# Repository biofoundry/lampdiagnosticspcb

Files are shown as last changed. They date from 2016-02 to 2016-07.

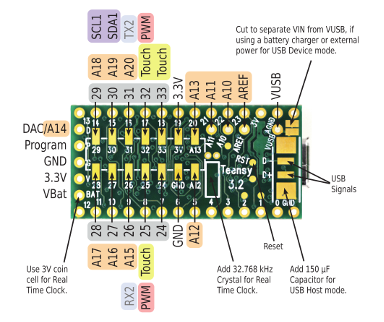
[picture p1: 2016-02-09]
Datasheets/teensy32_back_pinout.png

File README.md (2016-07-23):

# lampdiagnosticspcb
PCB Design for the LAMP Diagnostics device. Datasheets can be found in the Datasheet folder.

 My frist KiCAD project, sorry for any errors!

Based on a device built by Frank B. Myers, Richard H. Henrikson,Jennifer Bone and Luke P. Lee

http://journals.plos.org/plosone/article?id=10.1371/journal.pone.0070266
https://github.com/fbmyers/MicroBAR

This is a collaborative effort from bioHack Sydney and BioFoundry. 

Teensy's ADC / Voltage Reference
----------------

https://forum.pjrc.com/threads/27198-Using-External-AREF-with-ADC/page2

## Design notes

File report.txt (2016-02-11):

Info: Reading netlist file "/home/mat/lampdiagnosticspcb/projpcb.net".

Info: Using references to match components and footprints.

Info: Checking netlist component footprint "C1:/56B9C372:Capacitors_SMD:C_0805_HandSoldering".

Adding new component "C1:/56B9C372" footprint "Capacitors_SMD:C_0805_HandSoldering".

Changing component "C1:/56B9C372" pin "1" net name from "" to "VIN".

Changing component "C1:/56B9C372" pin "2" net name from "" to "GND".

Info: Checking netlist component footprint "C2:/56B9C865:Capacitors_SMD:C_0805_HandSoldering".

Adding new component "C2:/56B9C865" footprint "Capacitors_SMD:C_0805_HandSoldering".

Changing component "C2:/56B9C865" pin "1" net name from "" to "VIN".

Changing component "C2:/56B9C865" pin "2" net name from "" to "GND".

Info: Checking netlist component footprint "C3:/56B9CCA2:Capacitors_SMD:C_0805_HandSoldering".

Adding new component "C3:/56B9CCA2" footprint "Capacitors_SMD:C_0805_HandSoldering".

Changing component "C3:/56B9CCA2" pin "1" net name from "" to "+3V3".

Changing component "C3:/56B9CCA2" pin "2" net name from "" to "GND".

Info: Checking netlist component footprint "C4:/56B9CE8C:Capacitors_SMD:C_0805_HandSoldering".

Adding new component "C4:/56B9CE8C" footprint "Capacitors_SMD:C_0805_HandSoldering".

Changing component "C4:/56B9CE8C" pin "1" net name from "" to "+3V3".

Changing component "C4:/56B9CE8C" pin "2" net name from "" to "GND".

Info: Checking netlist component footprint "C5:/56B9CF34:Capacitors_SMD:C_0805_HandSoldering".

Adding new component "C5:/56B9CF34" footprint "Capacitors_SMD:C_0805_HandSoldering".

Changing component "C5:/56B9CF34" pin "1" net name from "" to "+3V3".

Changing component "C5:/56B9CF34" pin "2" net name from "" to "GND".

Info: Checking netlist component footprint "C6:/56B9E462:Capacitors_SMD:C_0805_HandSoldering".

Adding new component "C6:/56B9E462" footprint "Capacitors_SMD:C_0805_HandSoldering".

Changing component "C6:/56B9E462" pin "1" net name from "" to "+3V3".

Changing component "C6:/56B9E462" pin "2" net name from "" to "GND".

Info: Checking netlist component footprint "CON1:/56BA3485:Connect:BARREL_JACK".

Adding new component "CON1:/56BA3485" footprint "Connect:BARREL_JACK".

Changing component "CON1:/56BA3485" pin "1" net name from "" to "HEATER_PWR".

Changing component "CON1:/56BA3485" pin "2" net name from "" to "GND".

Changing component "CON1:/56BA3485" pin "3" net name from "" to "Net-(CON1-Pad3)".

Info: Checking netlist component footprint "CON2:/56BA4035:Connect:BARREL_JACK".

Adding new component "CON2:/56BA4035" footprint "Connect:BARREL_JACK".

Changing component "CON2:/56BA4035" pin "1" net name from "" to "HEATER_PWR".

Changing component "CON2:/56BA4035" pin "2" net name from "" to "Net-(CON2-Pad2)".

Changing component "CON2:/56BA4035" pin "3" net name from "" to "Net-(CON2-Pad3)".

Info: Checking netlist component footprint "P1:/56BA5A45:Pin_Headers:Pin_Header_Straight_1x02".

Adding new component "P1:/56BA5A45" footprint "Pin_Headers:Pin_Header_Straight_1x02".

Changing component "P1:/56BA5A45" pin "1" net name from "" to "VIN".

Changing component "P1:/56BA5A45" pin "2" net name from "" to "TEMP_S".

Info: Checking netlist component footprint "P2:/56BA95A4:Pin_Headers:Pin_Header_Angled_1x02".

Adding new component "P2:/56BA95A4" footprint "Pin_Headers:Pin_Header_Angled_1x02".

Changing component "P2:/56BA95A4" pin "1" net name from "" to "GND".

Changing component "P2:/56BA95A4" pin "2" net name from "" to "Net-(P2-Pad2)".

Info: Checking netlist component footprint "Q1:/56B9494D/56B94958:Resistors_SMD:R_0805_HandSoldering".

Adding new component "Q1:/56B9494D/56B94958" footprint "Resistors_SMD:R_0805_HandSoldering".

Changing component "Q1:/56B9494D/56B94958" pin "1" net name from "" to "/Phototransistors/S1".

Changing component "Q1:/56B9494D/56B94958" pin "2" net name from "" to "+3V3".

Info: Checking netlist component footprint "Q2:/56B9494D/56B94C7F:Resistors_SMD:R_0805_HandSoldering".

Adding new component "Q2:/56B9494D/56B94C7F" footprint "Resistors_SMD:R_0805_HandSoldering".

Changing component "Q2:/56B9494D/56B94C7F" pin "1" net name from "" to "/Phototransistors/S2".

Changing component "Q2:/56B9494D/56B94C7F" pin "2" net name from "" to "+3V3".

Info: Checking netlist component footprint "Q3:/56B9494D/56B94FE9:Resistors_SMD:R_0805_HandSoldering".

Adding new component "Q3:/56B9494D/56B94FE9" footprint "Resistors_SMD:R_0805_HandSoldering".

Changing component "Q3:/56B9494D/56B94FE9" pin "1" net name from "" to "/Phototransistors/S3".

Changing component "Q3:/56B9494D/56B94FE9" pin "2" net name from "" to "+3V3".

Info: Checking netlist component footprint "Q4:/56B9494D/56B950F7:Resistors_SMD:R_0805_HandSoldering".

Adding new component "Q4:/56B9494D/56B950F7" footprint "Resistors_SMD:R_0805_HandSoldering".

Changing component "Q4:/56B9494D/56B950F7" pin "1" net name from "" to "/Phototransistors/S4".

Changing component "Q4:/56B9494D/56B950F7" pin "2" net name from "" to "+3V3".

Info: Checking netlist component footprint "Q5:/56B9494D/56B951F6:Resistors_SMD:R_0805_HandSoldering".

Adding new component "Q5:/56B9494D/56B951F6" footprint "Resistors_SMD:R_0805_HandSoldering".

Changing component "Q5:/56B9494D/56B951F6" pin "1" net name from "" to "/Phototransistors/S5".

Changing component "Q5:/56B9494D/56B951F6" pin "2" net name from "" to "+3V3".

Info: Checking netlist component footprint "Q6:/56B9494D/56B94A26:Resistors_SMD:R_0805_HandSoldering".

Adding new component "Q6:/56B9494D/56B94A26" footprint "Resistors_SMD:R_0805_HandSoldering".

Changing component "Q6:/56B9494D/56B94A26" pin "1" net name from "" to "+3V3".

Changing component "Q6:/56B9494D/56B94A26" pin "2" net name from "" to "/Phototransistors/S6".

Info: Checking netlist component footprint "Q7:/56B9494D/56B94CFB:Resistors_SMD:R_0805_HandSoldering".

Adding new component "Q7:/56B9494D/56B94CFB" footprint "Resistors_SMD:R_0805_HandSoldering".

Changing component "Q7:/56B9494D/56B94CFB" pin "1" net name from "" to "/Phototransistors/S7".

Changing component "Q7:/56B9494D/56B94CFB" pin "2" net name from "" to "+3V3".

Info: Checking netlist component footprint "Q8:/56B9494D/56B94FEF:Resistors_SMD:R_0805_HandSoldering".

Adding new component "Q8:/56B9494D/56B94FEF" footprint "Resistors_SMD:R_0805_HandSoldering".

Changing component "Q8:/56B9494D/56B94FEF" pin "1" net name from "" to "/Phototransistors/S8".

Changing component "Q8:/56B9494D/56B94FEF" pin "2" net name from "" to "+3V3".

Info: Checking netlist component footprint "Q9:/56B9494D/56B950FD:Resistors_SMD:R_0805_HandSoldering".

Adding new component "Q9:/56B9494D/56B950FD" footprint "Resistors_SMD:R_0805_HandSoldering".

Changing component "Q9:/56B9494D/56B950FD" pin "1" net name from "" to "/Phototransistors/S9".

Changing component "Q9:/56B9494D/56B950FD" pin "2" net name from "" to "+3V3".

Info: Checking netlist component footprint "Q10:/56B9494D/56B951FC:Resistors_SMD:R_0805_HandSoldering".

Adding new component "Q10:/56B9494D/56B951FC" footprint "Resistors_SMD:R_0805_HandSoldering".

Changing component "Q10:/56B9494D/56B951FC" pin "1" net name from "" to "/Phototransistors/S10".

Changing component "Q10:/56B9494D/56B951FC" pin "2" net name from "" to "+3V3".

Info: Checking netlist component footprint "Q11:/56B9494D/56B94A86:Resistors_SMD:R_0805_HandSoldering".

Adding new component "Q11:/56B9494D/56B94A86" footprint "Resistors_SMD:R_0805_HandSoldering".

Changing component "Q11:/56B9494D/56B94A86" pin "1" net name from "" to "+3V3".

Changing component "Q11:/56B9494D/56B94A86" pin "2" net name from "" to "/Phototransistors/S11".

Info: Checking netlist component footprint "Q12:/56B9494D/56B94D59:Resistors_SMD:R_0805_HandSoldering".

Adding new component "Q12:/56B9494D/56B94D59" footprint "Resistors_SMD:R_0805_HandSoldering".

Changing component "Q12:/56B9494D/56B94D59" pin "1" net name from "" to "/Phototransistors/S12".

Changing component "Q12:/56B9494D/56B94D59" pin "2" net name from "" to "+3V3".

Info: Checking netlist component footprint "Q13:/56B9494D/56B94FF5:Resistors_SMD:R_0805_HandSoldering".

Adding new component "Q13:/56B9494D/56B94FF5" footprint "Resistors_SMD:R_0805_HandSoldering".

Changing component "Q13:/56B9494D/56B94FF5" pin "1" net name from "" to "/Phototransistors/S13".

Changing component "Q13:/56B9494D/56B94FF5" pin "2" net name from "" to "+3V3".

Info: Checking netlist component footprint "Q14:/56B9494D/56B95103:Resistors_SMD:R_0805_HandSoldering".

Adding new component "Q14:/56B9494D/56B95103" footprint "Resistors_SMD:R_0805_HandSoldering".

Changing component "Q14:/56B9494D/56B95103" pin "1" net name from "" to "/Phototransistors/S14".

Changing component "Q14:/56B9494D/56B95103" pin "2" net name from "" to "+3V3".

Info: Checking netlist component footprint "Q15:/56B9494D/56B95202:Resistors_SMD:R_0805_HandSoldering".

Adding new component "Q15:/56B9494D/56B95202" footprint "Resistors_SMD:R_0805_HandSoldering".

Changing component "Q15:/56B9494D/56B95202" pin "1" net name from "" to "/Phototransistors/S15".

Changing component "Q15:/56B9494D/56B95202" pin "2" net name from "" to "+3V3".

Info: Checking netlist component footprint "Q16:/56BA1661:TO_SOT_Packages_SMD:SOT-23_Handsoldering".

Adding new component "Q16:/56BA1661" footprint "TO_SOT_Packages_SMD:SOT-23_Handsoldering".

Changing component "Q16:/56BA1661" pin "1" net name from "" to "HEAT".

Changing component "Q16:/56BA1661" pin "2" net name from "" to "GND".

Changing component "Q16:/56BA1661" pin "3" net name from "" to "Net-(CON2-Pad2)".

Info: Checking netlist component footprint "R1:/56B99A73:Resistors_SMD:R_0805_HandSoldering".

Adding new component "R1:/56B99A73" footprint "Resistors_SMD:R_0805_HandSoldering".

Changing component "R1:/56B99A73" pin "1" net name from "" to "Net-(R1-Pad1)".

Changing component "R1:/56B99A73" pin "2" net name from "" to "GND".

Info: Checking netlist component footprint "R2:/56BA539F:Resistors_SMD:R_0805_HandSoldering".

Adding new component "R2:/56BA539F" footprint "Resistors_SMD:R_0805_HandSoldering".

Changing component "R2:/56BA539F" pin "1" net name from "" to "TEMP_S".

Changing component "R2:/56BA539F" pin "2" net name from "" to "GND".

Info: Checking netlist component footprint "RV1:/56B99053:Potentiometers:Potentiometer_Trimmer-Suntan-TSR-3386P".

Adding new component "RV1:/56B99053" footprint "Potentiometers:Potentiometer_Trimmer-Suntan-TSR-3386P".

Changing component "RV1:/56B99053" pin "3" net name from "" to "Net-(RV1-Pad3)".

Changing component "RV1:/56B99053" pin "1" net name from "" to "Net-(R1-Pad1)".

Changing component "RV1:/56B99053" pin "2" net name from "" to "Net-(R1-Pad1)".

Info: Checking netlist component footprint "RV2:/56B985A4:Potentiometers:Potentiometer_Trimmer-Suntan-TSR-3386P".

Adding new component "RV2:/56B985A4" footprint "Potentiometers:Potentiometer_Trimmer-Suntan-TSR-3386P".

Changing component "RV2:/56B985A4" pin "3" net name from "" to "GND".

Changing component "RV2:/56B985A4" pin "1" net name from "" to "Net-(RV2-Pad1)".

Changing component "RV2:/56B985A4" pin "2" net name from "" to "Net-(RV2-Pad1)".

Info: Checking netlist component footprint "U1:/56B935F7:Teensy-3:Teensy-3.1".

Adding new component "U1:/56B935F7" footprint "Teensy-3:Teensy-3.1".

Changing component "U1:/56B935F7" pin "0" net name from "" to "Net-(U1-Pad0)".

Changing component "U1:/56B935F7" pin "1" net name from "" to "Net-(U1-Pad1)".

Changing component "U1:/56B935F7" pin "2" net name from "" to "T2".

Changing component "U1:/56B935F7" pin "3" net name from "" to "T3".

Changing component "U1:/56B935F7" pin "4" net name from "" to "T4".

Changing component "U1:/56B935F7" pin "5" net name from "" to "T5".

Changing component "U1:/56B935F7" pin "6" net name from "" to "T6".

Changing component "U1:/56B935F7" pin "7" net name from "" to "HEAT".

Changing component "U1:/56B935F7" pin "8" net name from "" to "Net-(U1-Pad8)".

Changing component "U1:/56B935F7" pin "9" net name from "" to "Net-(U1-Pad9)".

Changing component "U1:/56B935F7" pin "10" net name from "" to "Net-(U1-Pad10)".

Changing component "U1:/56B935F7" pin "11" net name from "" to "Net-(U1-Pad11)".

Changing component "U1:/56B935F7" pin "12" net name from "" to "Net-(U1-Pad12)".

Changing component "U1:/56B935F7" pin "13" net name from "" to "Net-(U1-Pad13)".

Changing component "U1:/56B935F7" pin "14" net name from "" to "Net-(U1-Pad14)".

Changing component "U1:/56B935F7" pin "15" net name from "" to "Net-(U1-Pad15)".

Changing component "U1:/56B935F7" pin "16" net name from "" to "Net-(U1-Pad16)".

Changing component "U1:/56B935F7" pin "17" net name from "" to "Net-(U1-Pad17)".

Changing component "U1:/56B935F7" pin "18" net name from "" to "Net-(U1-Pad18)".

Changing component "U1:/56B935F7" pin "19" net name from "" to "Net-(U1-Pad19)".

Changing component "U1:/56B935F7" pin "20" net name from "" to "Net-(RV1-Pad3)".

Changing component "U1:/56B935F7" pin "21" net name from "" to "TEMP_S".

Changing component "U1:/56B935F7" pin "22" net name from "" to "Net-(U1-Pad22)".

Changing component "U1:/56B935F7" pin "23" net name from "" to "Net-(U1-Pad23)".

Changing component "U1:/56B935F7" pin "24" net name from "" to "Net-(U1-Pad24)".

Changing component "U1:/56B935F7" pin "25" net name from "" to "Net-(U1-Pad25)".

Changing component "U1:/56B935F7" pin "26" net name from "" to "VIN".

Changing component "U1:/56B935F7" pin "27" net name from "" to "Net-(U1-Pad27)".

Info: Checking netlist component footprint "U2:/56B98142:Housings_DIP:DIP-8_W7.62mm".

Adding new component "U2:/56B98142" footprint "Housings_DIP:DIP-8_W7.62mm".

Changing component "U2:/56B98142" pin "1" net name from "" to "Net-(RV1-Pad3)".

Changing component "U2:/56B98142" pin "2" net name from "" to "Net-(R1-Pad1)".

Changing component "U2:/56B98142" pin "3" net name from "" to "Net-(RV2-Pad1)".

Changing component "U2:/56B98142" pin "4" net name from "" to "VIN".

Changing component "U2:/56B98142" pin "8" net name from "" to "GND".

Info: Checking netlist component footprint "U3:/56B96E51:Housings_DIP:DIP-24_W10.16mm".

Adding new component "U3:/56B96E51" footprint "Housings_DIP:DIP-24_W10.16mm".

Changing component "U3:/56B96E51" pin "1" net name from "" to "Net-(RV2-Pad1)".

Changing component "U3:/56B96E51" pin "2" net name from "" to "/Phototransistors/S8".

Changing component "U3:/56B96E51" pin "3" net name from "" to "/Phototransistors/S7".

Changing component "U3:/56B96E51" pin "4" net name from "" to "/Phototransistors/S6".

Changing component "U3:/56B96E51" pin "5" net name from "" to "/Phototransistors/S5".

Changing component "U3:/56B96E51" pin "6" net name from "" to "/Phototransistors/S4".

Changing component "U3:/56B96E51" pin "7" net name from "" to "/Phototransistors/S3".

Changing component "U3:/56B96E51" pin "8" net name from "" to "/Phototransistors/S2".

Changing component "U3:/56B96E51" pin "9" net name from "" to "/Phototransistors/S1".

Changing component "U3:/56B96E51" pin "10" net name from "" to "T2".

Changing component "U3:/56B96E51" pin "11" net name from "" to "T3".

Changing component "U3:/56B96E51" pin "12" net name from "" to "GND".

Changing component "U3:/56B96E51" pin "13" net name from "" to "T5".

Changing component "U3:/56B96E51" pin "14" net name from "" to "T4".

Changing component "U3:/56B96E51" pin "15" net name from "" to "T6".

Changing component "U3:/56B96E51" pin "16" net name from "" to "Net-(U3-Pad16)".

Changing component "U3:/56B96E51" pin "17" net name from "" to "/Phototransistors/S15".

Changing component "U3:/56B96E51" pin "18" net name from "" to "/Phototransistors/S14".

Changing component "U3:/56B96E51" pin "19" net name from "" to "/Phototransistors/S13".

Changing component "U3:/56B96E51" pin "20" net name from "" to "/Phototransistors/S12".

Changing component "U3:/56B96E51" pin "21" net name from "" to "/Phototransistors/S11".

Changing component "U3:/56B96E51" pin "22" net name from "" to "/Phototransistors/S10".

Changing component "U3:/56B96E51" pin "23" net name from "" to "/Phototransistors/S9".

Changing component "U3:/56B96E51" pin "24" net name from "" to "VIN".

Info: Checking netlist component footprint "U4:/56BA8B71:TO_SOT_Packages_THT:TO-92_Inline_Narrow_Oval".

Adding new component "U4:/56BA8B71" footprint "TO_SOT_Packages_THT:TO-92_Inline_Narrow_Oval".

Changing component "U4:/56BA8B71" pin "2" net name from "" to "Net-(P2-Pad2)".

Changing component "U4:/56BA8B71" pin "3" net name from "" to "VIN".

Changing component "U4:/56BA8B71" pin "1" net name from "" to "GND".

Error: Component 'U1' pad '30' not found in footprint 'Teensy-3:Teensy-3.1'

Error: Component 'U1' pad '31' not found in footprint 'Teensy-3:Teensy-3.1'

Error: Component 'U1' pad '29' not found in footprint 'Teensy-3:Teensy-3.1'

Error: Component 'U1' pad '28' not found in footprint 'Teensy-3:Teensy-3.1'

Error: Component 'U1' pad '32' not found in footprint 'Teensy-3:Teensy-3.1'

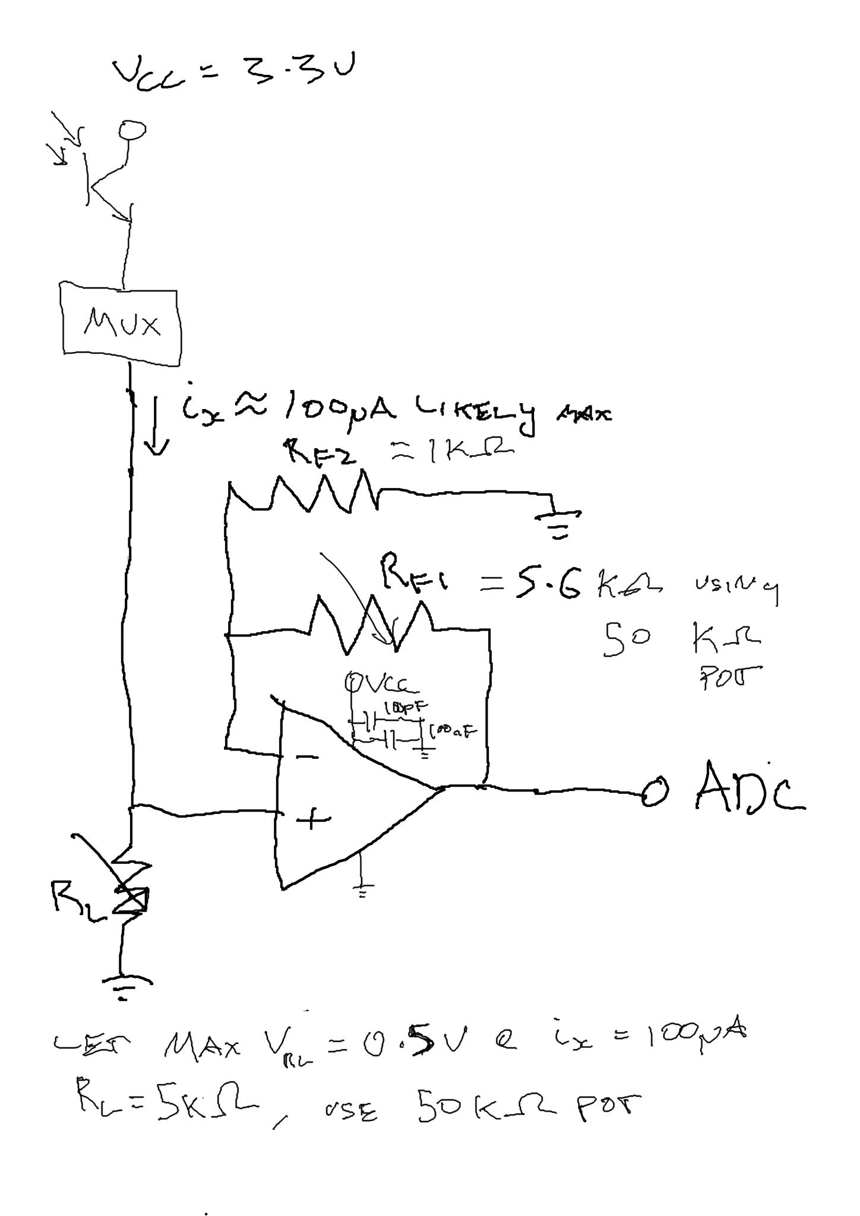
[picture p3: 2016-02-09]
Datasheets/InitialOpAmpLayout.jpg

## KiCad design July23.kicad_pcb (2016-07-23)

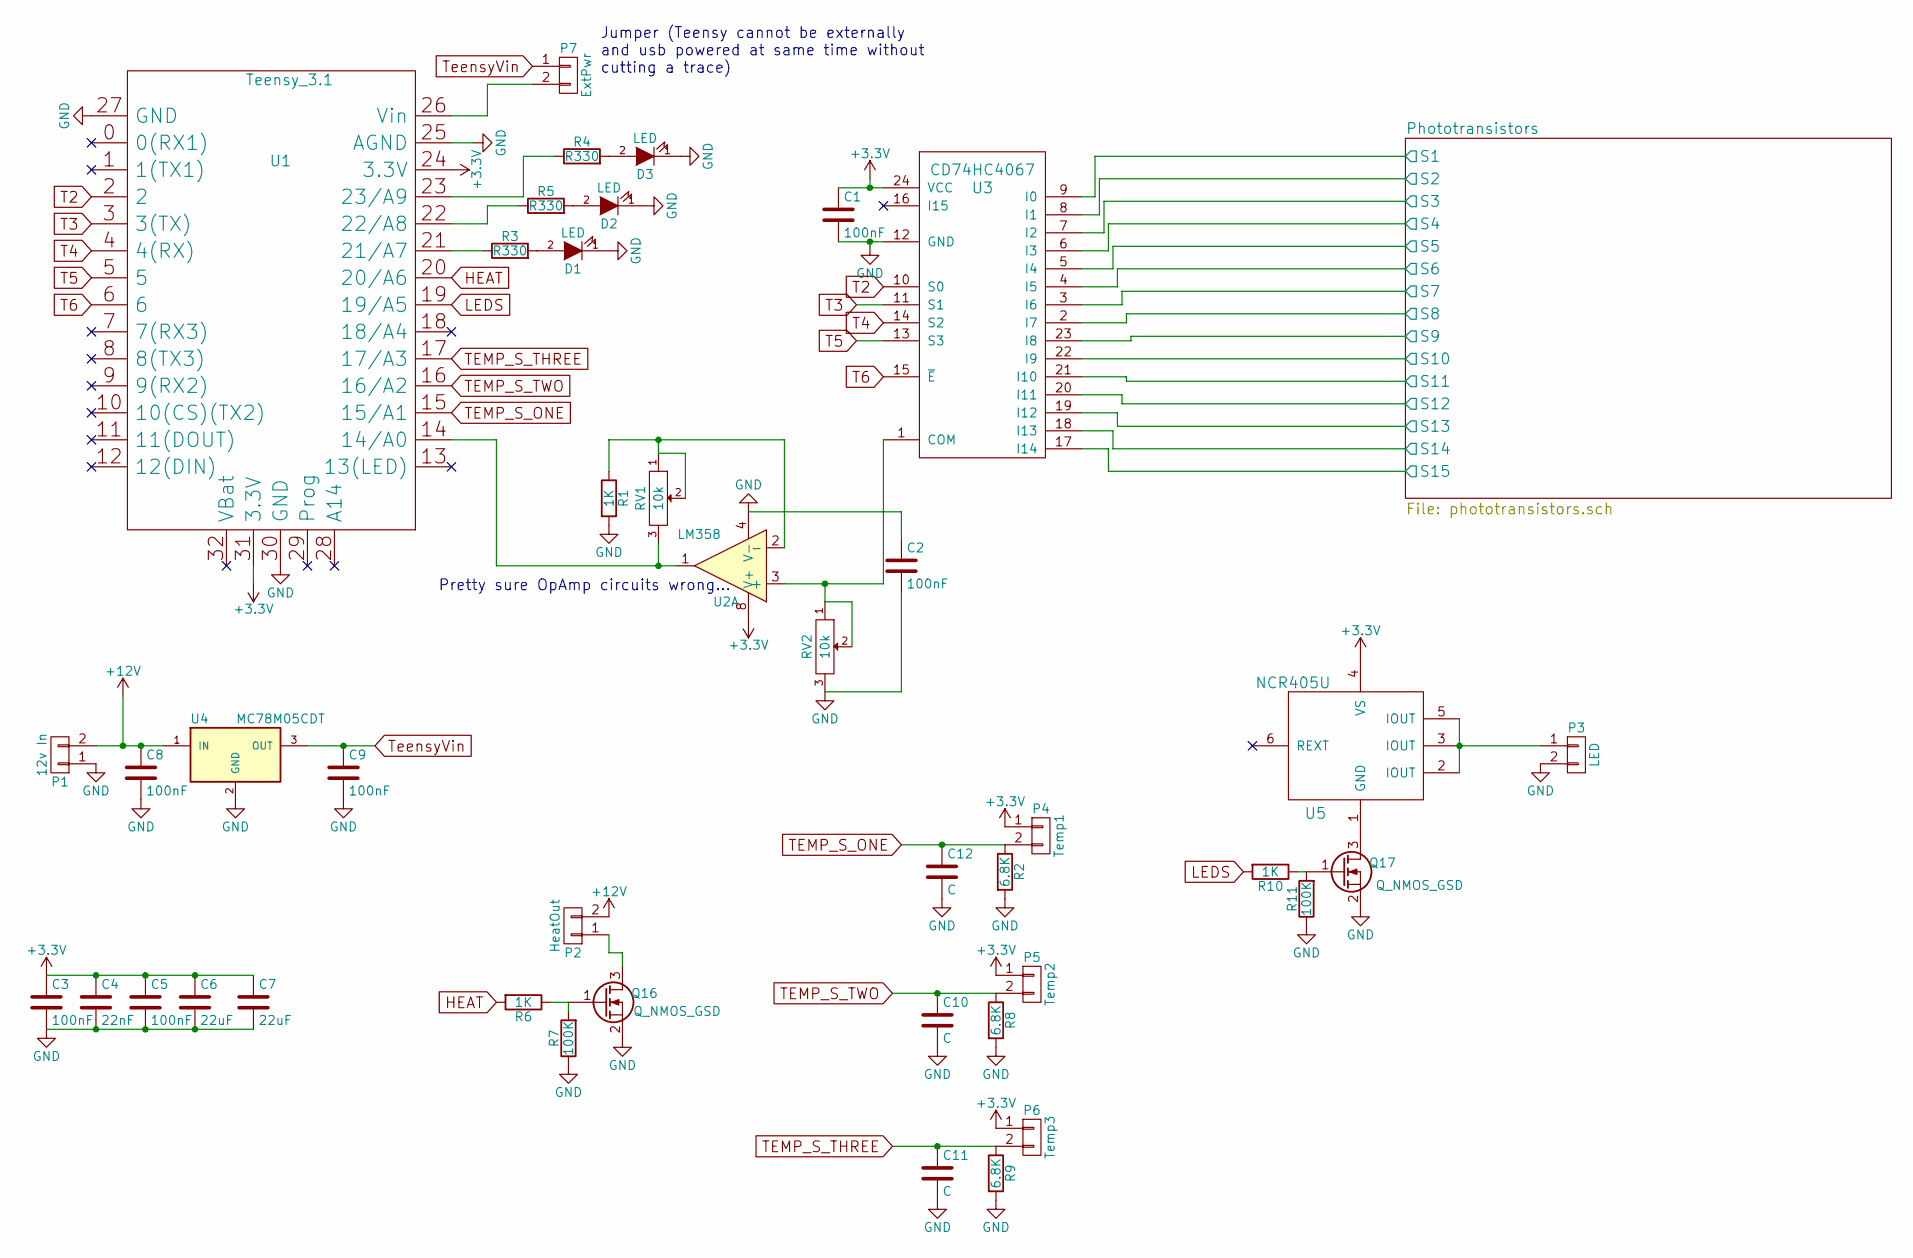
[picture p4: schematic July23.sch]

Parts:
C1, C2, C3, C5, C8, C9: 100nF; C_0805_HandSoldering
C4: 22nF; C_0805_HandSoldering
C6, C7: 22uF; C_0805_HandSoldering
C10, C11, C12: C; C_0805_HandSoldering
D1, D2, D3: LED; LED_0805
P1: 12v In; 2_5mm_screw_terminal
P2: HeatOut; 2_5mm_screw_terminal
P3: LED; 2_5mm_screw_terminal
P4: Temp1; 2_5mm_screw_terminal
P5: Temp2; 2_5mm_screw_terminal
P6: Temp3; 2_5mm_screw_terminal
P7: ExtPwr; Pin_Header_Straight_1x02
Q16, Q17: Q_NMOS_GSD; SOT-23_Handsoldering
R1, R6, R10: 1K; R_0805_HandSoldering
R2, R8, R9: 6.8K; R_0805_HandSoldering
R3, R4, R5: R330; R_0805_HandSoldering
R7, R11: 100K; R_0805_HandSoldering
RV1, RV2: 10k; Potentiometer_Trimmer-Suntan-TSR-3386P
U1: Teensy_3.1; Teensy-3.1
U2: LM358; DIP-8_W7.62mm
U3: CD74HC4067; DIP-24_W10.16mm
U4: MC78M05CDT; TO-252-2Lead
U5: NCR405U; SOT457

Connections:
+12V: C8.1, P1.2, P2.2, U4.1 (IN)
/Phototransistors/S1: U3.9 (I0); also elsewhere on the board
/Phototransistors/S2: U3.8 (I1); also elsewhere on the board
/Phototransistors/S3: U3.7 (I2); also elsewhere on the board
/Phototransistors/S4: U3.6 (I3); also elsewhere on the board
/Phototransistors/S5: U3.5 (I4); also elsewhere on the board
/Phototransistors/S6: U3.4 (I5); also elsewhere on the board
/Phototransistors/S7: U3.3 (I6); also elsewhere on the board
/Phototransistors/S8: U3.2 (I7); also elsewhere on the board
/Phototransistors/S9: U3.23 (I8); also elsewhere on the board
/Phototransistors/S10: U3.22 (I9); also elsewhere on the board
/Phototransistors/S11: U3.21 (I10); also elsewhere on the board
/Phototransistors/S12: U3.20 (I11); also elsewhere on the board
/Phototransistors/S13: U3.19 (I12); also elsewhere on the board
/Phototransistors/S14: U3.18 (I13); also elsewhere on the board
/Phototransistors/S15: U3.17 (I14); also elsewhere on the board
HEAT: R6.2, U1.20 (20/A6)
LEDS: R10.2, U1.19 (19/A5)
unnamed: D1.2 (A), R3.2
unnamed: D2.2 (A), R5.2
unnamed: D3.2 (A), R4.2
unnamed: P2.1, Q16.3 (D)
unnamed: P3.1, U5.2 (IOUT), U5.3 (IOUT), U5.5 (IOUT)
unnamed: P7.2, U1.26 (Vin)
unnamed: Q16.1 (G), R6.1, R7.2
unnamed: Q17.1 (G), R10.1, R11.2
unnamed: Q17.3 (D), U5.1 (GND)
unnamed: R1.1, RV1.1, RV1.2, U2.2 (-)
unnamed: R3.1, U1.21 (21/A7)
unnamed: R4.1, U1.23 (23/A9)
unnamed: R5.1, U1.22 (22/A8)
unnamed: RV1.3, U1.14 (14/A0), U2.1
unnamed: RV2.1, RV2.2, U2.3 (+), U3.1 (COM)
T2: U1.2, U3.10 (S0)
T3: U1.3 (3(TX)), U3.11 (S1)
T4: U1.4 (4(RX)), U3.14 (S2)
T5: U1.5, U3.13 (S3)
T6: U1.6, U3.15 (~E)
TEMP_S_ONE: C12.1, P4.2, R2.1, U1.15 (15/A1)
TEMP_S_THREE: C11.1, P6.2, R9.1, U1.17 (17/A3)
TEMP_S_TWO: C10.1, P5.2, R8.1, U1.16 (16/A2)
TeensyVin: C9.1, P7.1, U4.3 (OUT)

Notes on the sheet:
Jumper (Teensy cannot be externally and usb powered at same time without cutting a trace)
Pretty sure OpAmp circuits wrong...

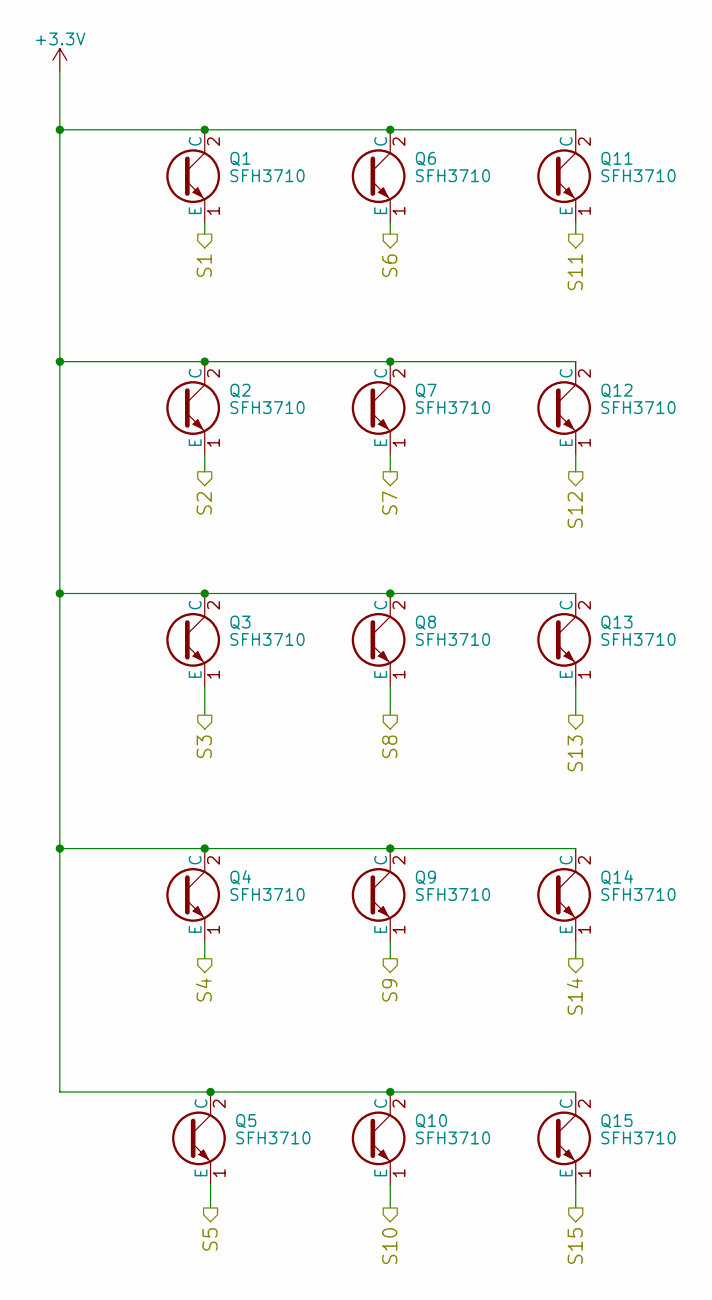
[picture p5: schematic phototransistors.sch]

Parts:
Q1, Q2, Q3, Q4, Q5, Q6, Q7, Q8, Q9, Q10, Q11, Q12, Q13, Q14, Q15: SFH3710; R_0805_HandSoldering

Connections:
/Phototransistors/S1: Q1.1 (E); also elsewhere on the board
/Phototransistors/S2: Q2.1 (E); also elsewhere on the board
/Phototransistors/S3: Q3.1 (E); also elsewhere on the board
/Phototransistors/S4: Q4.1 (E); also elsewhere on the board
/Phototransistors/S5: Q5.1 (E); also elsewhere on the board
/Phototransistors/S6: Q6.1 (E); also elsewhere on the board
/Phototransistors/S7: Q7.1 (E); also elsewhere on the board
/Phototransistors/S8: Q8.1 (E); also elsewhere on the board
/Phototransistors/S9: Q9.1 (E); also elsewhere on the board
/Phototransistors/S10: Q10.1 (E); also elsewhere on the board
/Phototransistors/S11: Q11.1 (E); also elsewhere on the board
/Phototransistors/S12: Q12.1 (E); also elsewhere on the board
/Phototransistors/S13: Q13.1 (E); also elsewhere on the board
/Phototransistors/S14: Q14.1 (E); also elsewhere on the board
/Phototransistors/S15: Q15.1 (E); also elsewhere on the board

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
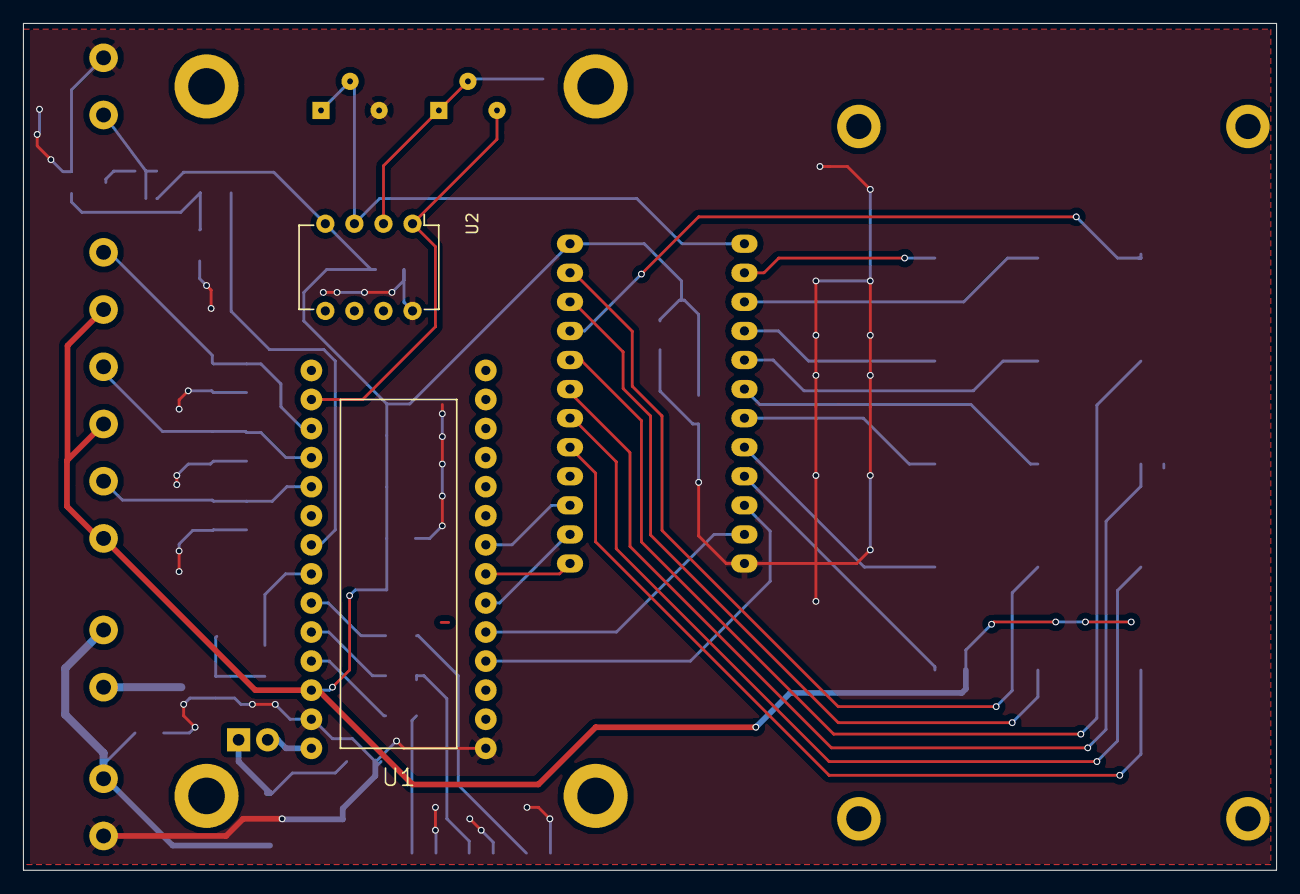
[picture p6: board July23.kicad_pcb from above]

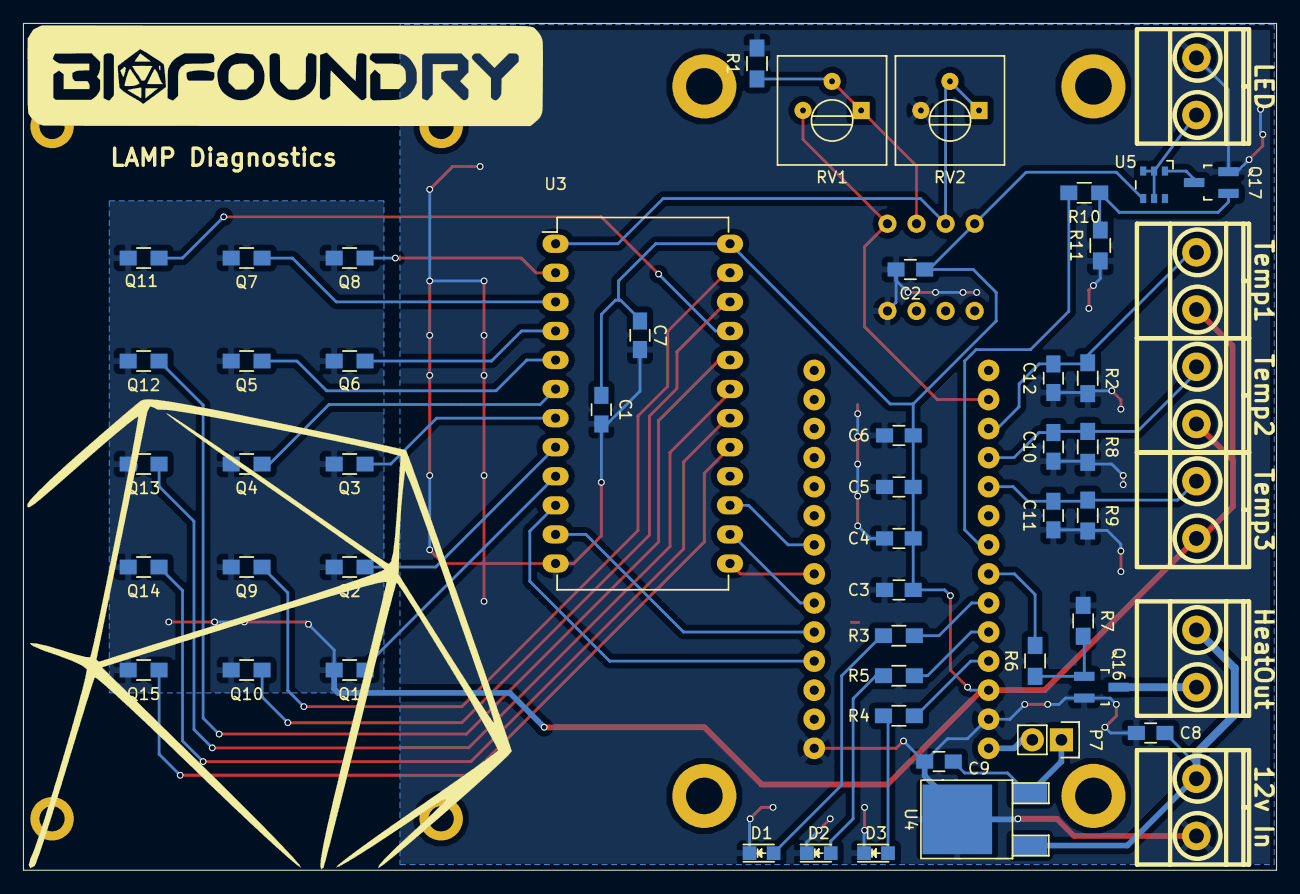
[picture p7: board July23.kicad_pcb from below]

Board: 2 copper layers, 109.5 x 74.0 mm, 57 parts (55 on the bottom side), 44 nets.

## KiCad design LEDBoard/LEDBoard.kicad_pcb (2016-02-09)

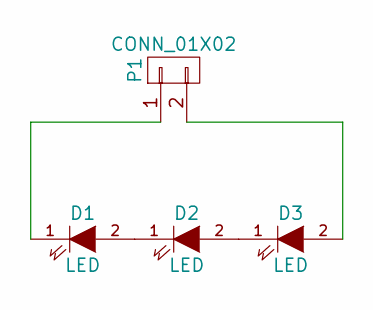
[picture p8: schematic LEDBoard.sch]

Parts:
D1, D2, D3: LED; LED-5MM
P1: CONN_01X02; Pin_Header_Straight_1x02

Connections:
unnamed: D1.1 (K), P1.1
unnamed: D1.2 (A), D2.1 (K)
unnamed: D2.2 (A), D3.1 (K)
unnamed: D3.2 (A), P1.2

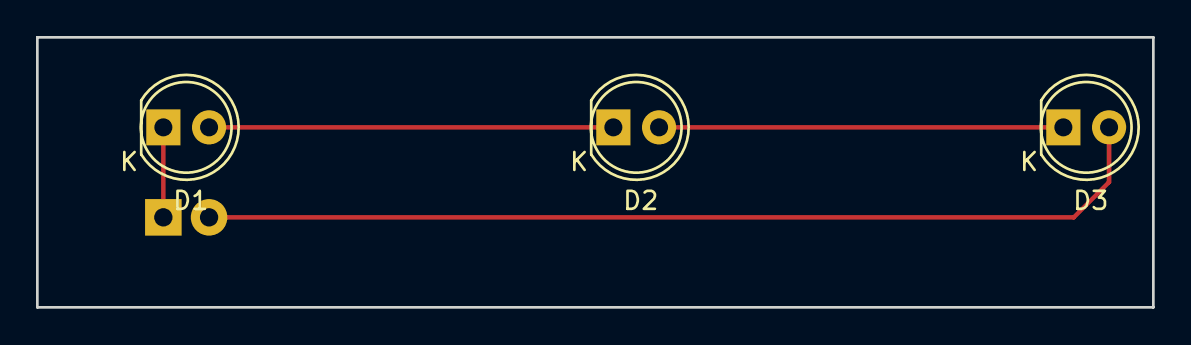
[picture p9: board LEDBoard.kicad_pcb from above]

Board: 2 copper layers, 62.0 x 15.0 mm, 4 parts (1 on the bottom side), 4 nets.

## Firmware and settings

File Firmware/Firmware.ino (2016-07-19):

/*

LAMP Diagnostics qPCR Device
Created by BioFoundry

Contributers --Mat(fluffeh) Neal -- Tom -- Sophie -- Meow -- Nicole -- James -- 

Status LEDS's Green(15) Blue(14) Red (16)
 
 */
 
// Pin 13 has an LED connected on most Arduino boards.
// Pin 11 has the LED on Teensy 2.0
// Pin 6  has the LED on Teensy++ 2.0
// Pin 13 has the LED on Teensy 3.0
// give it a name:

int ledG = 15;
int ledB = 14;
int ledR = 16;

// the setup routine runs once when you press reset:
void setup() {                
  // initialize the digital pin as an output.
  pinMode(ledR, OUTPUT);
  pinMode(ledG, OUTPUT);    
  pinMode(ledB, OUTPUT);     

  delay(500);

  digitalWrite(ledR, HIGH);  
  delay(1000);               
  digitalWrite(ledR, LOW);   


  digitalWrite(ledG, HIGH);  
  delay(1000);               
  digitalWrite(ledG, LOW);   


  digitalWrite(ledB, HIGH);  
  delay(1000);               
  digitalWrite(ledB, LOW);   

                 
}

// the loop routine runs over and over again forever:
void loop() {
  digitalWrite(ledR, HIGH);  
  delay(50);               
  digitalWrite(ledR, LOW);

  digitalWrite(ledG, HIGH);  
  delay(50);               
  digitalWrite(ledG, LOW);  

  digitalWrite(ledB, HIGH);  
  delay(50);               
  digitalWrite(ledB, LOW); 

  


 
}

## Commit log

2016-02-09 Created project file
    [projpcb.kicad_pcb, projpcb.sch]
2016-02-09 New footprint for teensy
2016-02-09 schematic so far
    [phototransistors.sch, projpcb.sch]
2016-02-09 Progress on schematic, phototransistor array + analog frontend complete
    [phototransistors.sch, projpcb.sch]
2016-02-09 Draft version v1 of Schematic
    [phototransistors.sch, projpcb.sch]
2016-02-11 Board design V1
    [projpcb.kicad_pcb, projpcb.sch]
2016-02-20 Added breakout headers for phototransistors, added GNDA for analog aspects
    [_saved_projpcb.sch, pcbSpaced.kicad_pcb, phototransistors.sch]
2016-02-24 Changed VIN --> 3.3v, analog GND to AGND, added 3 status LED's
    [_saved_projpcb.sch, phototransistors.sch, projpcb.kicad_pcb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]
2016-02-24 PCB furtherererd
    [projpcb.kicad_pcb]
2016-03-11 VERSION ONE - Sent for manufacturegit add -Agit add -A
    [DONNE-B.Cu.gbl, DONNE-B.Mask.gbs, DONNE-B.SilkS.gbo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]
2016-07-19 Added missing pot, logos and mounting holes.
    [July18.kicad_pcb, phototransistors.sch, projpcb.sch]
2016-07-19 Deleted redundant files. July 18 Pro / Board files are latest. Next step is firmware
    [DONNE.kicad_pcb, Done??.kicad_pcb, pcbSpaced.kicad_pcb]
2016-07-19 More via stitching, more bypass for mux
    [July18.kicad_pcb, phototransistors.sch, projpcb.sch]
2016-07-19 Blarg, KiCAD crashed, redoing all before, repushing often
    [July18.kicad_pcb]
2016-07-21 Big revamp
    Added mosfet to LED output
    Changed LED driver to NCR405U
    Changed phototransistor array to be 9mm * 9mm to match standard 96 well
    sizing
    Added 5v Linear reg to feed the teensy as well as a jumper so we can do
    initial tests using usb power
    [July18.kicad_pcb, phototransistors.sch, projpcb.sch]
2016-07-21 Added Name ^.^
    [July18.kicad_pcb]
2016-07-22 Moved via ^.^
    [July18.kicad_pcb]
2016-07-23 Cleaned up Old files
    [July18.kicad_pcb, July23.kicad_pcb, July23.sch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]
2016-07-23 Changed schematic of SFH3710
    [July23.kicad_pcb, July23.sch, phototransistors.sch]
2016-07-23 OpAmp circuit needs checking
    [July23.kicad_pcb, July23.sch]
2016-07-26 opamp flipped for clarity
    [July23.sch]
2016-07-26 fixing up opamp on PCB (work in progress)
    [July23.kicad_pcb, July23.sch]
2016-07-28 improved Gnd stitching
    unused part of LM358 still to be connected somewhere
    [July23.kicad_pcb]
2016-07-30 bigger 3v3 tracks
    not sure if LED supply is better or worse now - it's away from the opamp (that's good), but now might cause interference on the temp. sensors (that's bad).
    If LED isn't switched much, and/or if temperature accuracy isn't critical, this layout should be OK.
    Might still be worth moving some of the 3v3 capacitors over to the phototransistors though.
